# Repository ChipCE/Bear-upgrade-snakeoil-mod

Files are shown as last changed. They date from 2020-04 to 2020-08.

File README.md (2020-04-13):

# Bear upgrade snakeoil mod
Custom parts based on  [gregsaun](https://github.com/gregsaun)'s awesome [bear_extruder_and_x_axi](https://github.com/gregsaun/bear_extruder_and_x_axis) and [prusa_i3_bear_upgrade](https://github.com/gregsaun/prusa_i3_bear_upgrade) for non-standard frame.

# Document and Required parts

- Will be updated on the next few days.

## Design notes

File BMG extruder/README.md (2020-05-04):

# "PTFE" FDM printable BMG Bondtech extruder for Prusa

 This design is based on [MarcoZ76's Bondtech BMG Upgrade MK3S FDM printable new sensor integrated](https://www.thingiverse.com/thing:3469271) and [Bondtech BMG Prusa MK3S/MK2.5S v2 FDM printable + RHD ver.C fan Shroud](https://www.thingiverse.com/thing:3754163/files) with some modify to maker the part easier to be printed with FDM printer, added PTFE tube as filament path to fix the jamming problem of non-smooth printed filament path.

### You will need [bear X axis](https://www.thingiverse.com/thing:3716110) for this extruder(v1).

## Feature

- Use PTFE tube instead of printed filament path that might cause jam if the printed path is not smooth enought.(v1 and v2)
- Lighter body(v1 mod)
- Custom support built in on STL(v1 and v2)
- Accessable to the gear for manual control.(v1 and v2)

## Require printed parts(v1)

| Part name | Link | Other option |
|---|---|---|
| Nozzle  duct | [MK3 RHD Fan Duct Rev. C](https://www.thingiverse.com/thing:3249344) | [Micro-tweaks to Nozzle RHD Rev C for Slic3r](https://www.thingiverse.com/thing:4054462) |
| Nozzle duct mounter | [MK3 Nozzle RHD Rev. C Support for FDM Printable Bondtech BMG](https://www.thingiverse.com/thing:3429508) | - |
| X carrier | [Bondtech_BMG_Upgrade_MK3S_sensor_Bear_carriage.stl](https://www.thingiverse.com/thing:3469271/files) | - |
| Body front | PTFE-BMG-body-front.stl |  |
| Body back | PTFE-BMG-body-back.stl | |
| Filament sensor level | 3469271__fs-level.stl | |
| Hingle | 3469271_Hinge_with_2mm_recession.stl | |
| Filament sensor cover | 3469271__Sensor_cover_PC4-M10_new.stl or 3469271__Sensor_cover_PC4-M6_new.stl | |
| PTFE cutter guide(base & cap) | PTFE-cutter-guide-base.stl & PTFE-cutter-guide-cap.stl | |

## Require printed parts(v2)

| Part name | Link | Other option |
|---|---|---|
| Nozzle  duct | [MK3 RHD Fan Duct Rev. C](https://www.thingiverse.com/thing:3249344) | [Micro-tweaks to Nozzle RHD Rev C for Slic3r](https://www.thingiverse.com/thing:4054462) |
| Nozzle duct mounter | [MK3 Nozzle RHD Rev. C Support for FDM Printable Bondtech BMG](https://www.thingiverse.com/thing:3429508) | - |
| X carrier | Bear Bondtech mounter | Standard bondtech carrier also work on stock mk3?(not tested) |
| Body front | v2-ptfe-body-front..stl |  |
| Body back | v2-ptfe-body-back.stl | |
| Filament sensor level | v2-fs-lever.stl | Use the fix version instead. This version has extend the level by 0.5mm to address the unstable trigger problem in the original design  |
| Sensor ballbearing adapter | v2-adapter-printer.stl | |
 Hingle | v2-hingle.stl |  |
| Filament sensor cover | v2-Sensor_Cover_MK3s.stl | v2-Sensor_Cover_MK3s-M5x08.STL, v2-Sensor_Cover_MK3s-M6x1.stl |
| PTFE cutter guide(base & cap) | PTFE-cutter-guide-base.stl & PTFE-cutter-guide-cap.stl |   |

## Require part

| Part name | Link |  |
|---|---|---|
| 1x Shaft Assembly  | https://www.bondtech.se/en/product/shaft-assembly |  |
| 2x Ball Bearing 5x8x2.5  | https://www.bondtech.se/en/product/ballbearing-5x8x2-5/ |  |
| 1x Motor Gear | https://www.bondtech.se/en/product/motor-gear/ |  |
| 1x 1.75 / 5.0 Bontech Drivergear kit. | b | No need if you own a MK3 |
| 1x Thumbscrew Assembly | https://www.bondtech.se/en/product-category/spare-parts/thumbscrew-assembly/ | Can use a long M3 bolt instead |

## Assemply guide

- You will need to use the ptfe cutting guide to cut and file down the ptfe tube. USe a small file or a rotaty tool to file down about 0.5mm the side of the tube.
- Other step is the same as on the Bondtech guide.

## Print setting(Prusa slicer)
- 0.2mm layer height
- No support

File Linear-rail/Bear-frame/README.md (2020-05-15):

# README.md

This mod will also lower the bed by 10mm.  
You will need modified Y-motor mount, Y-belt holder, Y - idler and LCD mounter to use with this mod.  
The block mounter require 12mm m3 spacers.  
The rails must be mounted on 2020 extrusion.

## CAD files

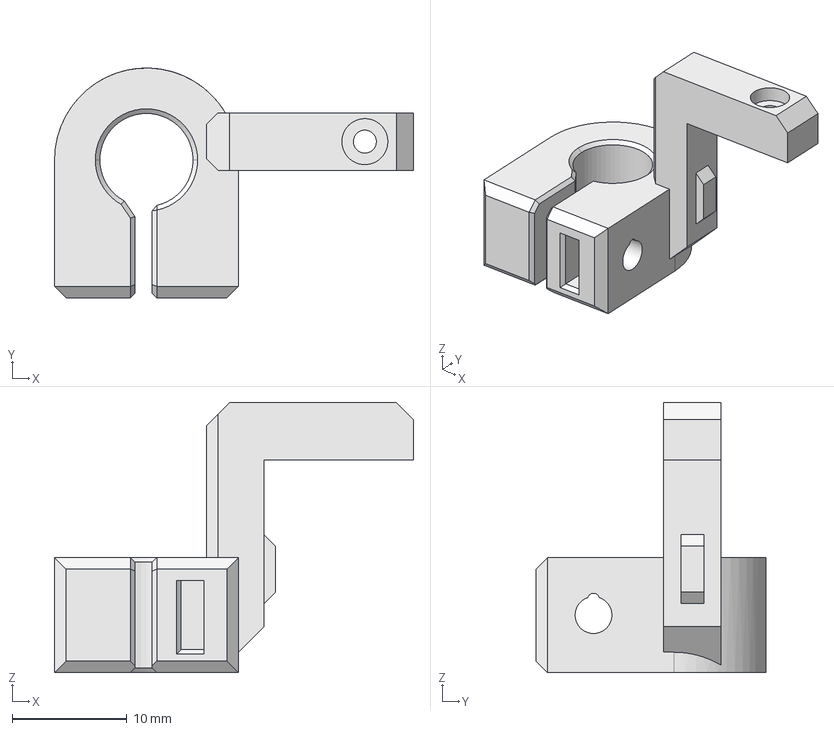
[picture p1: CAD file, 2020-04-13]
4020-fan-bearmera/step/probe-mount.step
31.2 x 20.0 x 23.5 mm

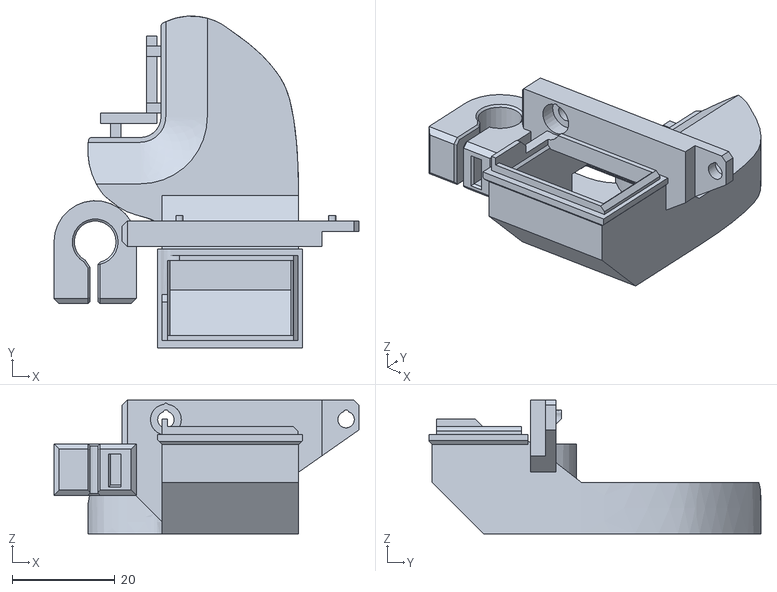
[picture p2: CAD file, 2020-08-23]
4020-fan-bearmera/stl/duct_probe.stl
59.2 x 64.5 x 26.0

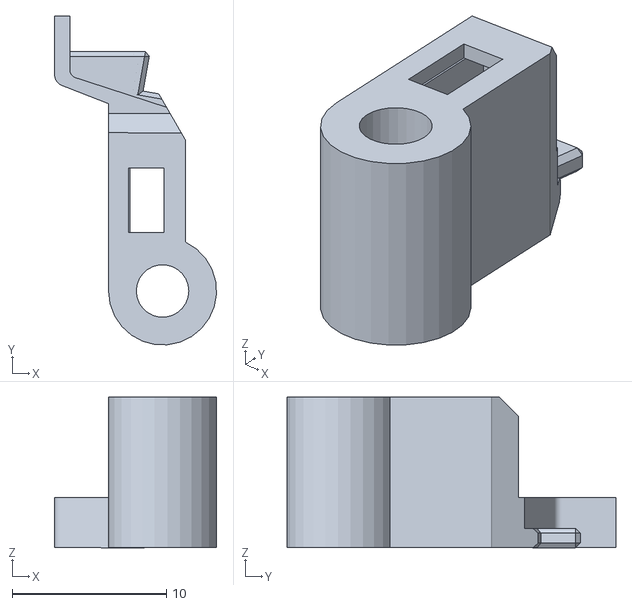
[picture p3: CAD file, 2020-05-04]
BMG extruder/v2/stl/v2-fs-lever-fix.stl
10.5 x 21.3 x 9.75

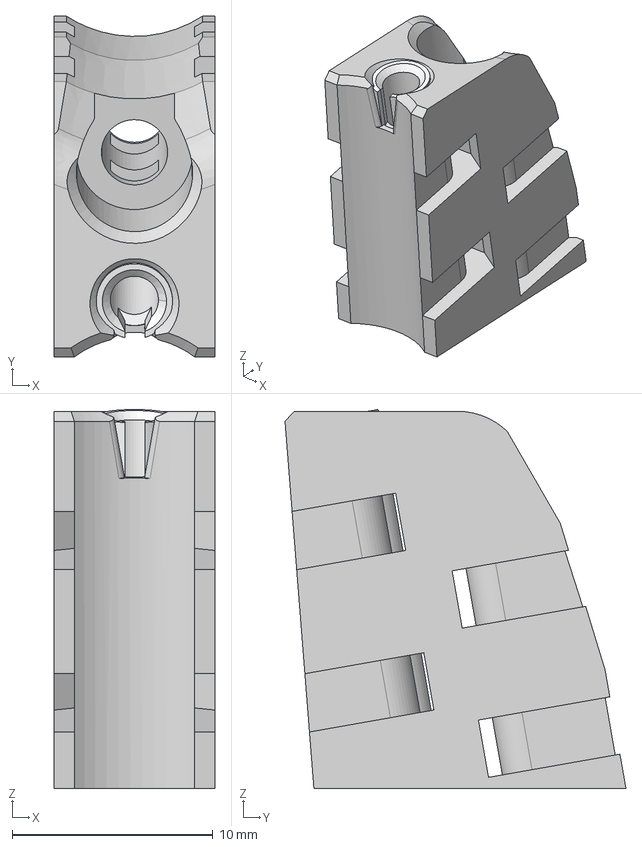
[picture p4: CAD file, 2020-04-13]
Extruder-cable-mounter-175/step/cable-mounter-175.step
8.00 x 17.0 x 18.9 mm

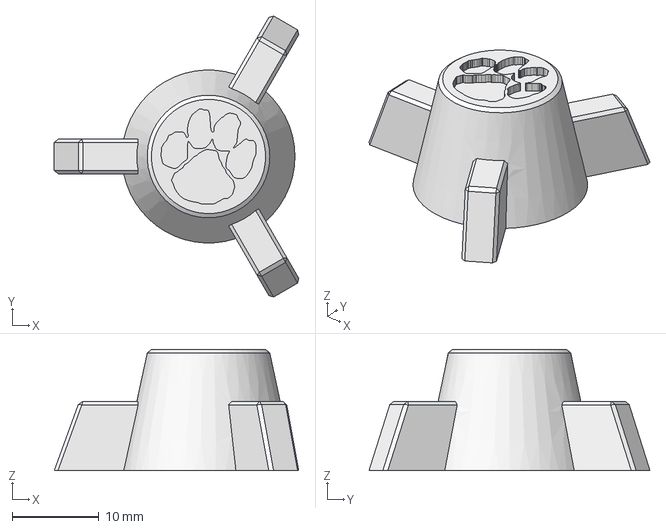
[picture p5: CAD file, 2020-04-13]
LCD-knob/step/knob.step
28.3 x 32.5 x 14.0 mm

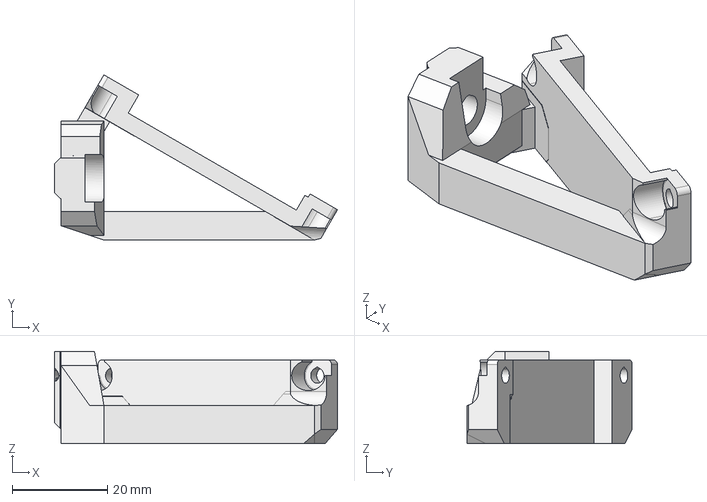
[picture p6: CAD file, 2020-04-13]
LCD-mounter/step/LCD-mounter.step
59.5 x 34.7 x 19.4 mm

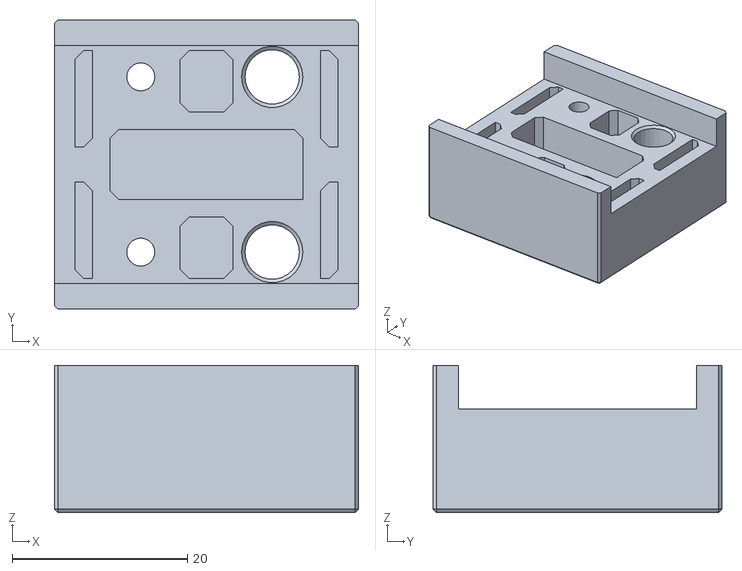
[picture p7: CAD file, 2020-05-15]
Linear-rail/Bear-frame/12C-block-mount.stl
34.7 x 33.0 x 16.8

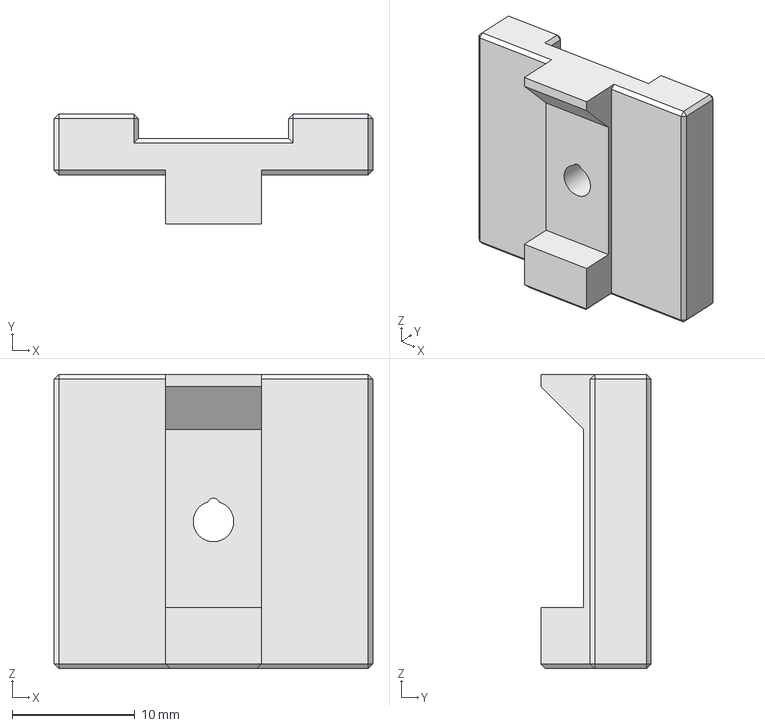
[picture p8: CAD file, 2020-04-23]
Linear-rail/Original-mk3-frame/v2/step/node-rev2.step
26.0 x 9.00 x 24.0 mm

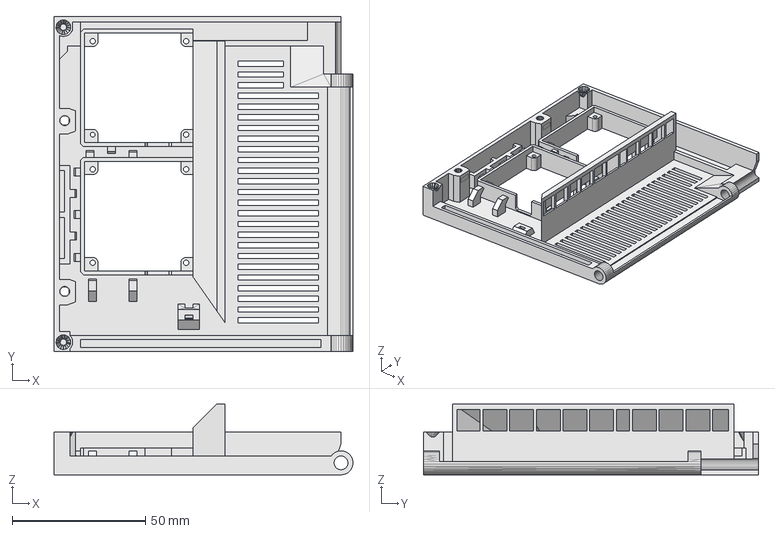
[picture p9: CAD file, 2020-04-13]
SKR-case/step/door.step
112.0 x 125.5 x 26.5 mm

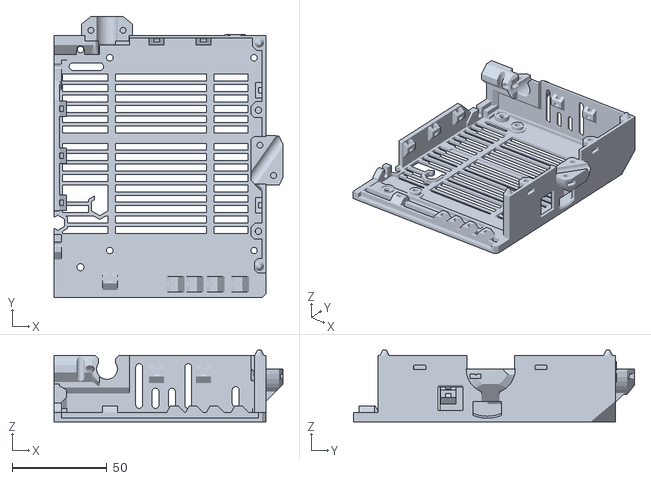
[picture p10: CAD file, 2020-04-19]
SKR-case/stl/base.stl
121.0 x 148.5 x 38.0

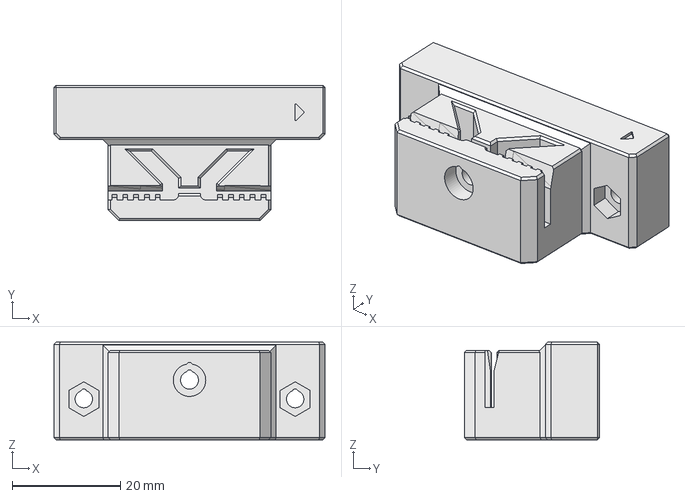
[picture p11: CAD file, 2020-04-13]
Y-belt-mounter/step/belt-mounter.step
50.0 x 25.0 x 18.0 mm

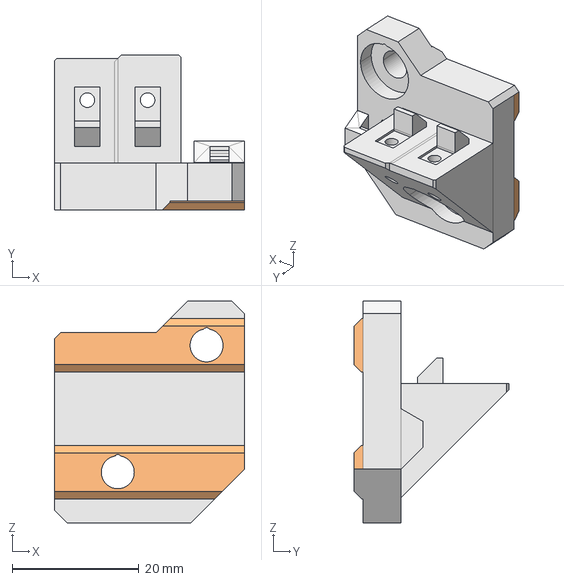
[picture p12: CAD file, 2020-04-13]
Y-end-stop/step/y-end-stop-mounter.step
30.0 x 24.4 x 35.0 mm

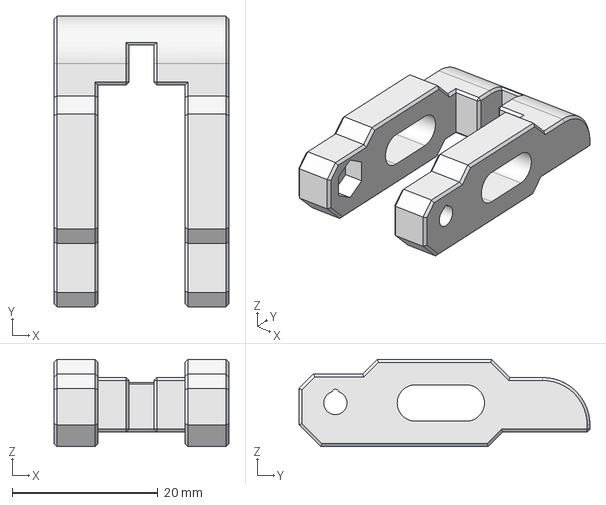
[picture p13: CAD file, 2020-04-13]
Y-idler-tensioner/step/arm.step
24.0 x 40.0 x 12.0 mm

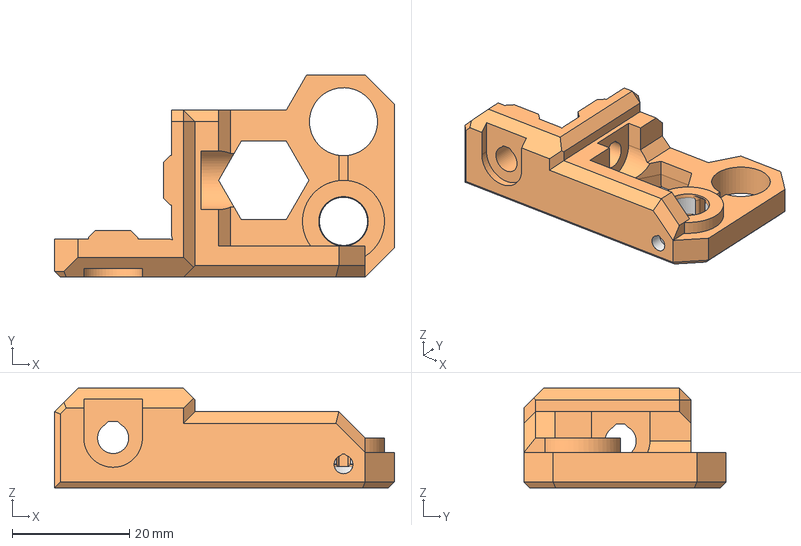
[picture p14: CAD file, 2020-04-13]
Z-top/step/z-top-left.step
58.0 x 34.5 x 17.0 mm

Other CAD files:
4020-fan-bearmera/step/body-front.step
BMG extruder/v2/stl/v2-hingle.stl
Linear-rail/Bear-frame/12h-block-mount.stl
Linear-rail/Original-mk3-frame/v2/step/head-rev2.step
4020-fan-bearmera/step/fan-duct.step
4020-fan-bearmera/stl/body-front.stl
BMG extruder/v1/stl/3249344_MK3_Nozzle_RHD_Rev-C.stl
BMG extruder/v1/stl/3429508_FDM_BMG_RHD_Fan_Nozzle_Support.stl
BMG extruder/v1/stl/3469271_Bondtech_BMG_Upgrade_MK3S_sensor_Bear_carriage.stl
BMG extruder/v1/stl/3469271_Hinge_with_2mm_recession.stl
BMG extruder/v1/stl/3469271__Sensor_cover_PC4-M10_new.stl
BMG extruder/v1/stl/3469271__Sensor_cover_PC4-M6_new.stl
BMG extruder/v1/stl/3469271__fs-level.stl
BMG extruder/v1/stl/PTFE-BMG-body-back.stl
BMG extruder/v1/stl/PTFE-BMG-front.stl
BMG extruder/v1/stl/PTFE-cutter-guide-base.stl
BMG extruder/v1/stl/PTFE-cutter-guide-cap.stl
BMG extruder/v2/stl/v2-Sensor_Cover_MK3s-M5x08.STL
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

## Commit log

2020-04-13 added cutter guide for leadscrew nut adapter
    [nut-cutter-guide.step, nut-cutter-guide.stl]
2020-04-19 added PTFE BMG extruder
    [3249344_MK3_Nozzle_RHD_Rev-C.stl, 3429508_FDM_BMG_RHD_Fan_Nozzle_Support.stl, 3469271_Bondtech_BMG_Upgrade_MK3S_sensor_Bear_carriage.stl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]
2020-04-19 fixed duplicate file
    [PTFE-BMG-body-front.stl, PTFE-BMG-front.stl]
2020-04-23 added railr-v2 and ptfe-bmg-v2
    [12C-block-mount-with-endtop.step, 12C-block-mount-with-endtop.stl, 12C-block.step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]
2020-05-04 added fixed level
    [v2-fs-lever-fix.stl]
2020-05-15 added linear rail mounter for bear frame
    [12C-block-mount-with-endtop.step, 12C-block-mount-with-endtop.stl, 12C-block-mount.stl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]
